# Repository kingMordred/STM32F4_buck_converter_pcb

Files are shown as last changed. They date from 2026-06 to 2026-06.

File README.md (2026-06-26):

# STM32F4_buck_converter_pcb

PCB design using KiCad 10.0 for an STM32F4 with a buck converter, usb connection, USART and I2c communication lines with the microcontroller and an external clock.

### Schematic overview


### Pcb overview


### Board 3D viewer


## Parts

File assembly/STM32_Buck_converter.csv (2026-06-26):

Reference | Qty | Value | DNP | Exclude from BOM | Exclude from Board | Footprint | Datasheet
C1,C2 | 2 | 2u2 |  |  |  | Capacitor_SMD:C_0603_1608Metric
C3 | 1 | 4u7 |  |  |  | Capacitor_SMD:C_0603_1608Metric
C4,C5,C6,C7,C8 | 5 | 100n |  |  |  | Capacitor_SMD:C_0402_1005Metric
C9 | 1 | 1u |  |  |  | Capacitor_SMD:C_0402_1005Metric
C10,C14 | 2 | 10n |  |  |  | Capacitor_SMD:C_0402_1005Metric
C11,C12 | 2 | 12p |  |  |  | Capacitor_SMD:C_0402_1005Metric
C13,C15,C16 | 3 | 10u |  |  |  | Capacitor_SMD:C_1206_3216Metric
D1 | 1 | BLUE |  |  |  | LED_SMD:LED_0603_1608Metric
D2,D3 | 2 | B5819W |  |  |  | Diode_SMD:D_SOD-123
D4 | 1 | RED |  |  |  | LED_SMD:LED_0603_1608Metric
F1 | 1 | 250mA |  |  |  | Fuse:Fuse_1206_3216Metric
FB1 | 1 | 600 @ 600MHz |  |  |  | Inductor_SMD:L_0805_2012Metric
J1 | 1 | Screw_Terminal_01x02 |  |  |  | TerminalBlock_Phoenix:TerminalBlock_Phoenix_PT-1,5-2-3.5-H_1x02_P3.50mm_Horizontal
J2 | 1 | SWD |  |  |  | Connector_PinHeader_1.27mm:PinHeader_2x05_P1.27mm_Vertical_SMD
J3,J4 | 2 | Conn_01x04 |  |  |  | Connector_Molex:Molex_PicoBlade_53048-0410_1x04_P1.25mm_Horizontal
J5 | 1 | USB_B_Micro |  |  |  | Connector_USB:USB_Micro-B_GCT_USB3076-30-A
L1 | 1 | 39n |  |  |  | Inductor_SMD:L_0402_1005Metric
L2 | 1 | 10u |  |  |  | Inductor_SMD:L_Sunlord_MWSA0503S
Q1 | 1 | AO3401A |  |  |  | Package_TO_SOT_SMD:SOT-23 | http://www.aosmd.com/pdfs/datasheet/AO3401A.pdf
R1 | 1 | 10k |  |  |  | Resistor_SMD:R_0402_1005Metric
R2 | 1 | 47 |  |  |  | Resistor_SMD:R_0402_1005Metric
R3 | 1 | 1k5 |  |  |  | Resistor_SMD:R_0603_1608Metric
R4 | 1 | 100k |  |  |  | Resistor_SMD:R_0603_1608Metric
R5 | 1 | 68k |  |  |  | Resistor_SMD:R_0603_1608Metric
R6 | 1 | 47k |  |  |  | Resistor_SMD:R_0603_1608Metric
R7 | 1 | 15k |  |  |  | Resistor_SMD:R_0603_1608Metric
R8 | 1 | 270 |  |  |  | Resistor_SMD:R_0603_1608Metric
R9,R10 | 2 | 2k2 |  |  |  | Resistor_SMD:R_0402_1005Metric
R11 | 1 | 1k |  |  |  | Resistor_SMD:R_0603_1608Metric
SW1 | 1 | SW_SPDT |  |  |  | Button_Switch_SMD:SW_SPDT_PCM12
U1 | 1 | STM32F405RGT6 |  |  |  | Package_QFP:LQFP-64_10x10mm_P0.5mm | https://www.st.com/resource/en/datasheet/stm32f405rg.pdf
U2 | 1 | MP2359DJ-LF-Z |  |  |  | Package_TO_SOT_SMD:SOT-23-6
U3 | 1 | USBLC6-2SC6 |  |  |  | Package_TO_SOT_SMD:SOT-23-6 | https://www.st.com/resource/en/datasheet/usblc6-2.pdf
Y1 | 1 | 16MHz |  |  |  | Crystal:Crystal_SMD_3225-4Pin_3.2x2.5mm

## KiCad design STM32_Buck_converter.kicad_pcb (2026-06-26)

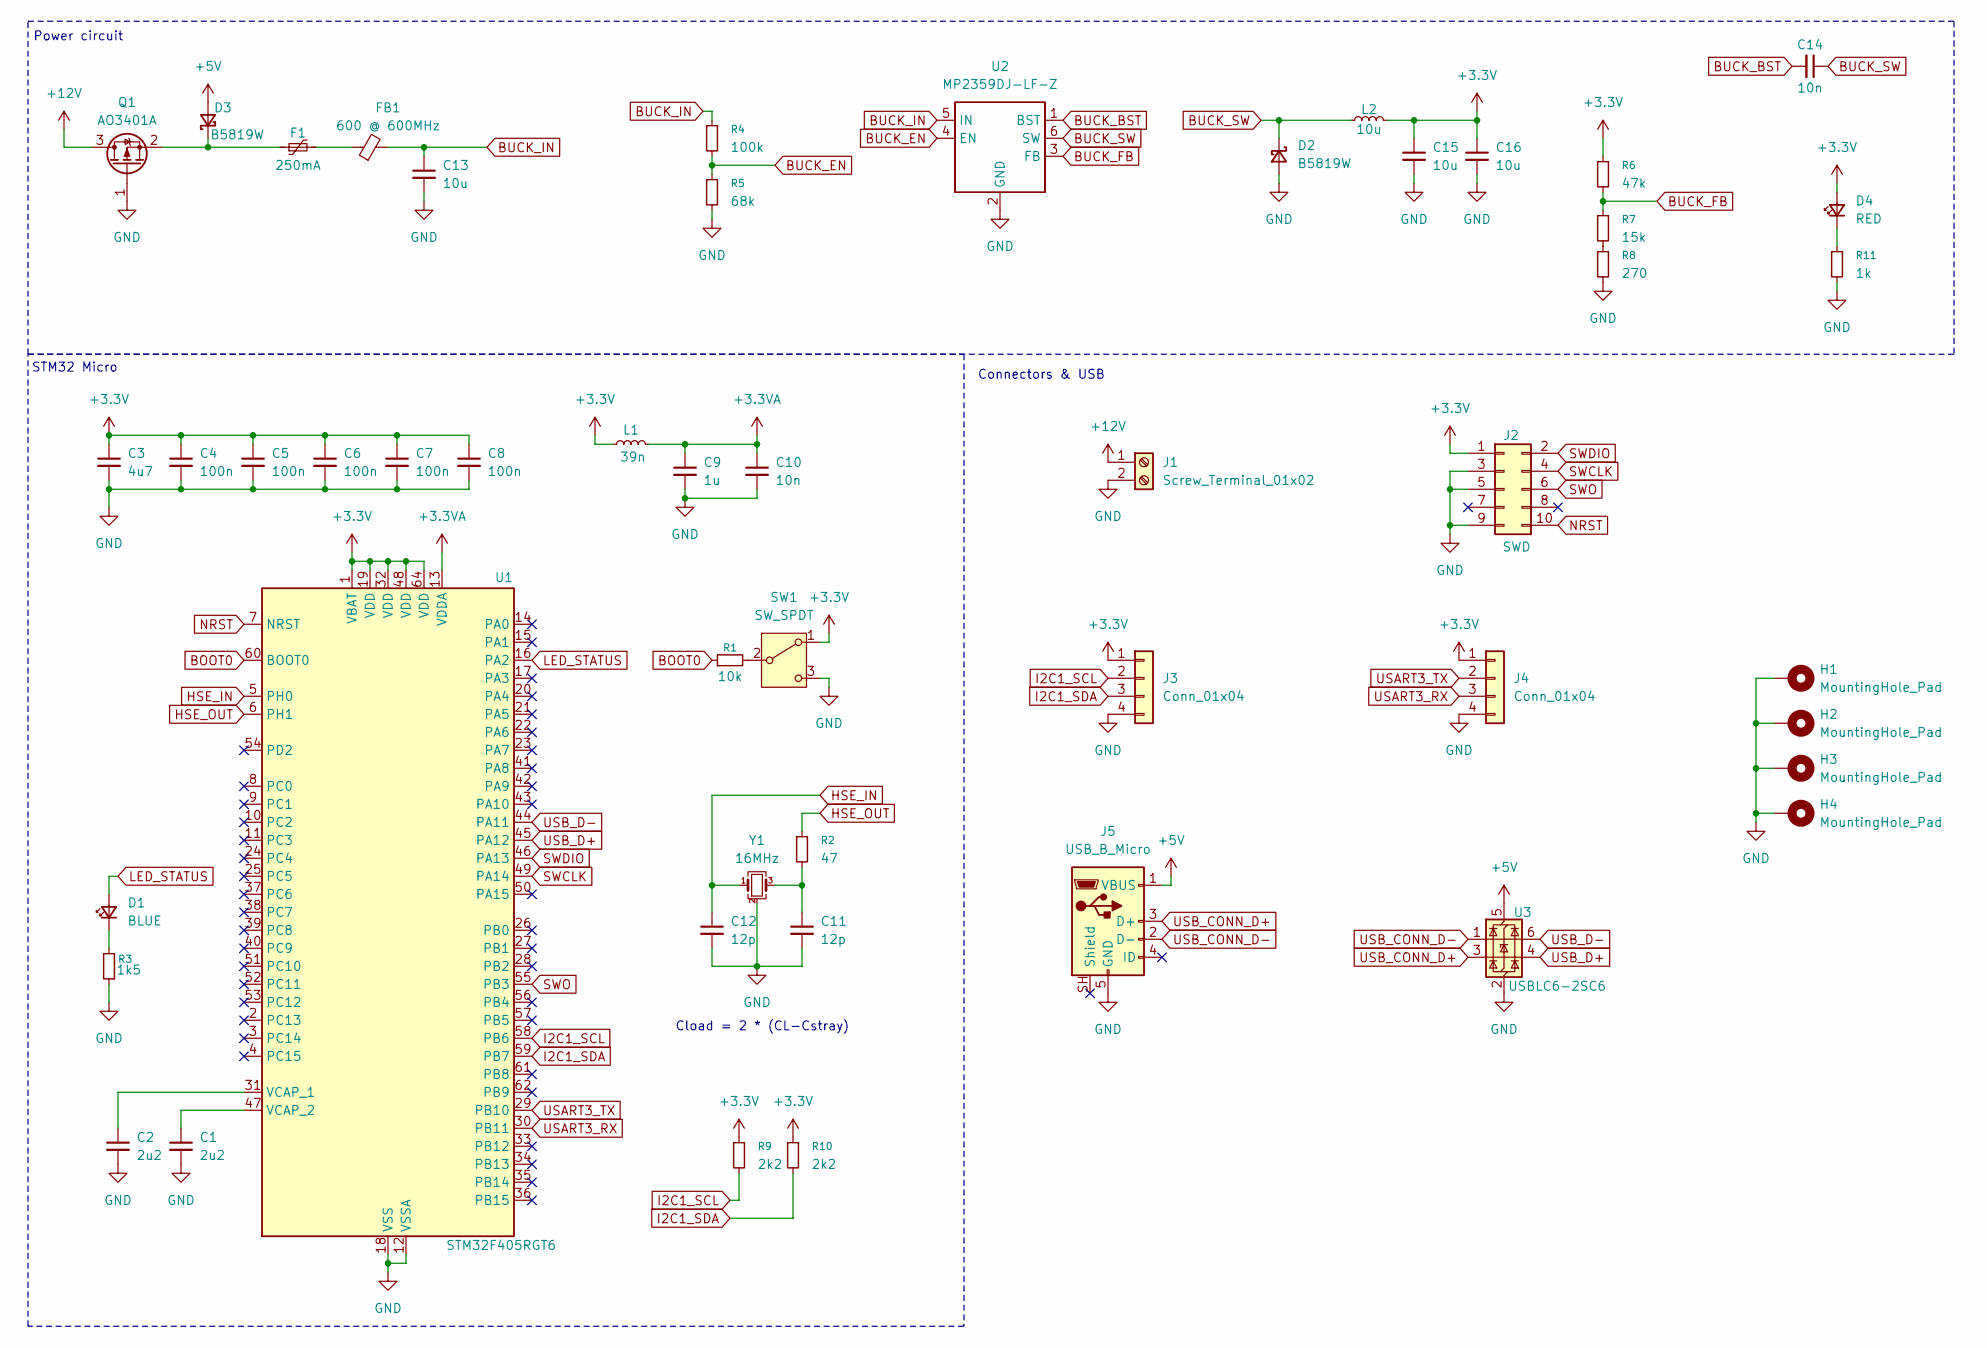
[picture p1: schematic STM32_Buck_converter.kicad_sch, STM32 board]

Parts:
C1, C2: 2u2; C_0603_1608Metric
C3: 4u7; C_0603_1608Metric
C4, C5, C6, C7, C8: 100n; C_0402_1005Metric
C9: 1u; C_0402_1005Metric
C10, C14: 10n; C_0402_1005Metric
C11, C12: 12p; C_0402_1005Metric
C13, C15, C16: 10u; C_1206_3216Metric
D1: BLUE; LED_0603_1608Metric
D2, D3: B5819W; D_SOD-123
D4: RED; LED_0603_1608Metric
F1: 250mA; Fuse_1206_3216Metric
FB1: 600 @ 600MHz; L_0805_2012Metric
H1, H2, H3, H4: MountingHole_Pad; MountingHole_4.3mm_M4_Pad_Via
J1: Screw_Terminal_01x02; TerminalBlock_Phoenix_PT-1,5-2-3.5-H_1x02_P3.50mm_Horizontal
J2: SWD; PinHeader_2x05_P1.27mm_Vertical_SMD
J3, J4: Conn_01x04; Molex_PicoBlade_53048-0410_1x04_P1.25mm_Horizontal
J5: USB_B_Micro; USB_Micro-B_GCT_USB3076-30-A
L1: 39n; L_0402_1005Metric
L2: 10u; L_Sunlord_MWSA0503S
Q1: AO3401A; SOT-23
R1: 10k; R_0402_1005Metric
R2: 47; R_0402_1005Metric
R3: 1k5; R_0603_1608Metric
R4: 100k; R_0603_1608Metric
R5: 68k; R_0603_1608Metric
R6: 47k; R_0603_1608Metric
R7: 15k; R_0603_1608Metric
R8: 270; R_0603_1608Metric
R9, R10: 2k2; R_0402_1005Metric
R11: 1k; R_0603_1608Metric
SW1: SW_SPDT; SW_SPDT_PCM12
U1: STM32F405RGT6; LQFP-64_10x10mm_P0.5mm
U2: MP2359DJ-LF-Z; SOT-23-6
U3: USBLC6-2SC6; SOT-23-6
Y1: 16MHz; Crystal_SMD_3225-4Pin_3.2x2.5mm

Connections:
+3.3V: C3.1, C4.1, C5.1, C6.1, C7.1, C8.1, C15.1, C16.1, D4.2 (A), J2.1, J3.1, J4.1, L1.1, L2.2, R6.1, R9.1, R10.1, SW1.1 (A), U1.1 (VBAT), U1.19 (VDD), U1.32 (VDD), U1.48 (VDD), U1.64 (VDD)
+3.3VA: C9.1, C10.1, L1.2, U1.13 (VDDA)
+5V: D3.2 (A), J5.1 (VBUS), U3.5 (VBUS)
+12V: J1.1, Q1.3 (D)
BOOT0: R1.1, U1.60 (BOOT0)
BUCK_BST: C14.2, U2.1 (BST)
BUCK_EN: R4.2, R5.1, U2.4 (EN)
BUCK_FB: R6.2, R7.1, U2.3 (FB)
BUCK_IN: C13.1, FB1.2, R4.1, U2.5 (IN)
BUCK_SW: C14.1, D2.1 (K), L2.1, U2.6 (SW)
GND: C1.2, C2.2, C3.2, C4.2, C5.2, C6.2, C7.2, C8.2, C9.2, C10.2, C11.2, C12.2, C13.2, C15.2, C16.2, D2.2 (A), H1.1 (1_1), H2.1 (1_1), H3.1 (1_1), H4.1 (1_1), J1.2, J2.3, J2.5, J2.9, J3.4, J4.4, J5.5 (GND), Q1.1 (G), R3.1, R5.2, R8.2, R11.2, SW1.3 (C), U1.12 (VSSA), U1.18 (VSS), U1.63 (VSS), U2.2 (GND), U3.2 (GND), Y1.2 (G), Y1.4 (G)
HSE_IN: C12.1, U1.5 (PH0), Y1.1
HSE_OUT: R2.1, U1.6 (PH1)
I2C1_SCL: J3.2, R9.2, U1.58 (PB6)
I2C1_SDA: J3.3, R10.2, U1.59 (PB7)
LED_STATUS: D1.2 (A), U1.16 (PA2)
NRST: J2.10, U1.7 (NRST)
unnamed: C11.1, R2.2, Y1.3
unnamed: D1.1 (K), R3.2
unnamed: D3.1 (K), F1.1, Q1.2 (S)
unnamed: D4.1 (K), R11.1
unnamed: F1.2, FB1.1
unnamed: R7.2, R8.1
unnamed: R1.2, SW1.2 (B)
unnamed: C2.1, U1.31 (VCAP_1)
unnamed: C1.1, U1.47 (VCAP_2)
SWCLK: J2.4, U1.49 (PA14)
SWDIO: J2.2, U1.46 (PA13)
SWO: J2.6, U1.55 (PB3)
USART3_RX: J4.3, U1.30 (PB11)
USART3_TX: J4.2, U1.29 (PB10)
USB_CONN_D+: J5.3 (D+), U3.3 (I/O2)
USB_CONN_D-: J5.2 (D-), U3.1 (I/O1)
USB_D+: U1.45 (PA12), U3.4 (I/O2)
USB_D-: U1.44 (PA11), U3.6 (I/O1)

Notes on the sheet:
STM32 Micro
Cload = 2 * (CL-Cstray)
Connectors & USB
Power circuit

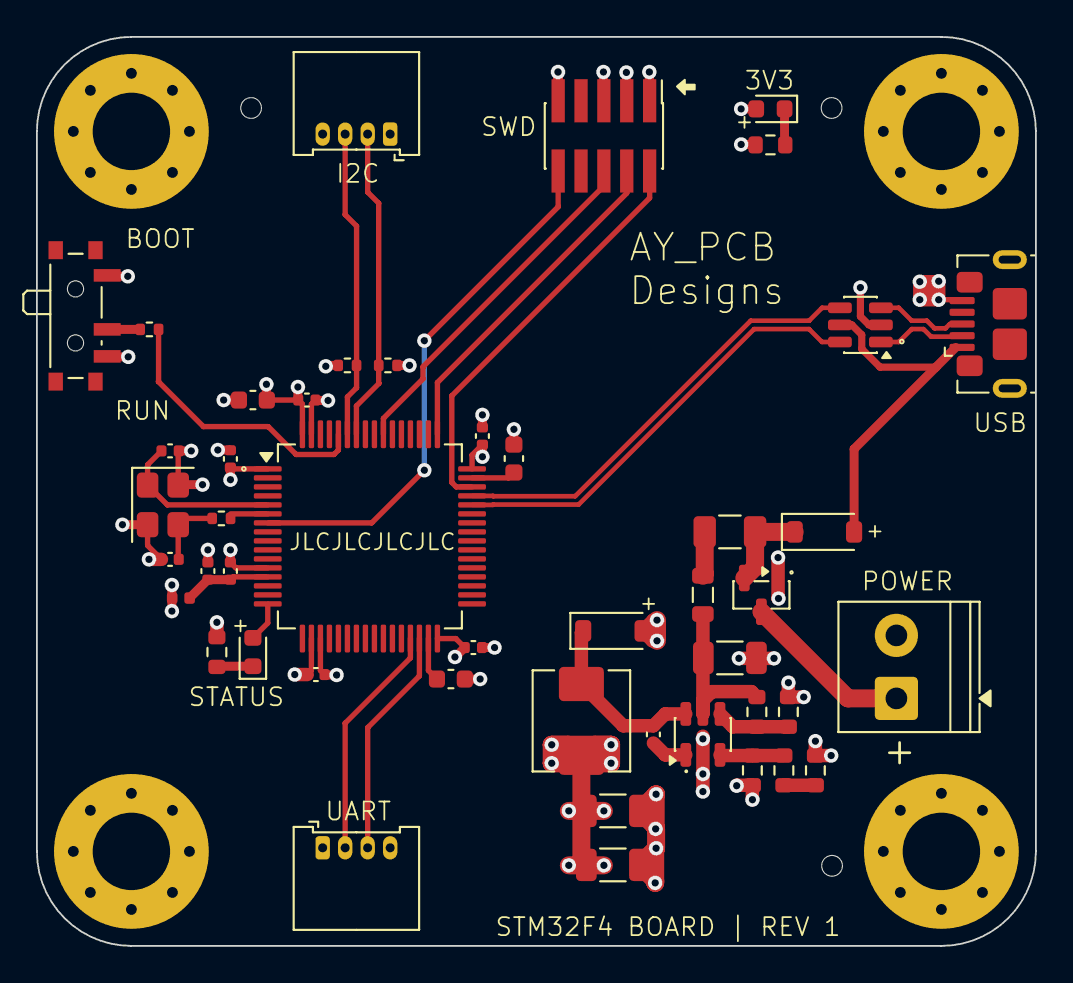
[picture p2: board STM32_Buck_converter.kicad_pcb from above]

Board: 4 copper layers, 55.5 x 50.5 mm, 50 parts (0 on the bottom side), 35 nets.

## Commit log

2026-06-26 STM32 buck converter board pcb design - Rev 1
    [STM32_Buck_converter-B_Cu.gbr, STM32_Buck_converter-B_Mask.gbr, STM32_Buck_converter-B_Paste.gbr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]
2026-06-26 Update README
    Added detailed project description and images for schematic, PCB, and 3D viewer.
